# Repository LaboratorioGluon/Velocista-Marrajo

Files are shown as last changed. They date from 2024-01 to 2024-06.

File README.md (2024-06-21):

# Velocista Marrajo

Robot velocista para competición.

## Componentes Principales

- ESC 4-en-1: https://s.click.aliexpress.com/e/_DDoQeDV
- Motores Ruedas (2004 1750KV): https://es.aliexpress.com/item/1005005199386587.html
- Motor Succion (GR1404 3850KV):  https://s.click.aliexpress.com/e/_DeUeUJD
- Procesador (ESP32): https://s.click.aliexpress.com/e/_DCxmJWF
- Sensores (ITR8307): https://s.click.aliexpress.com/e/_DEY47Gr
- Rodamientos (MR128 8x12x3.5, x4): https://s.click.aliexpress.com/e/_DeULPyP
- Engranaje (7T 1.48mm): https://s.click.aliexpress.com/e/_DDH1tE3
- Engranaje (423A, x2): https://s.click.aliexpress.com/e/_DeBl3bN

## Renders

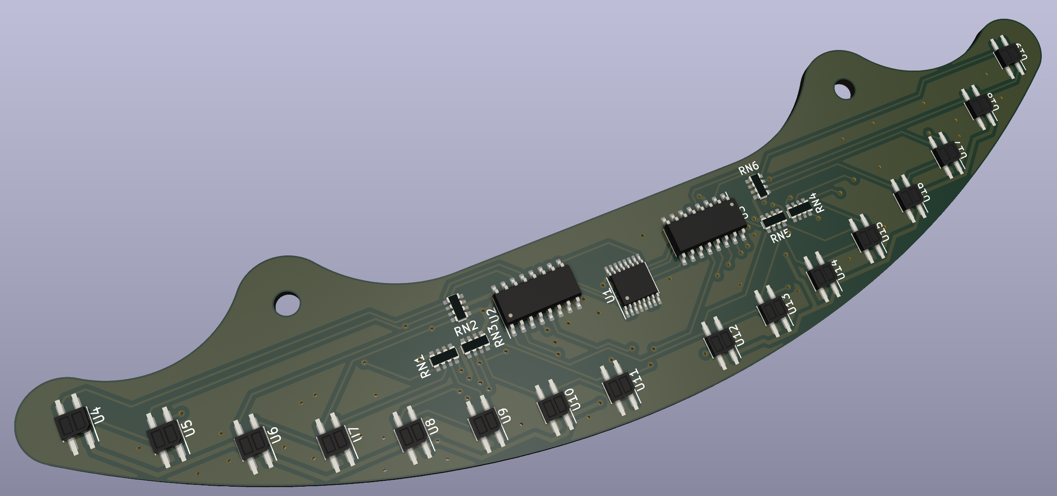
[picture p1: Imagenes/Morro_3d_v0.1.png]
Render Morro


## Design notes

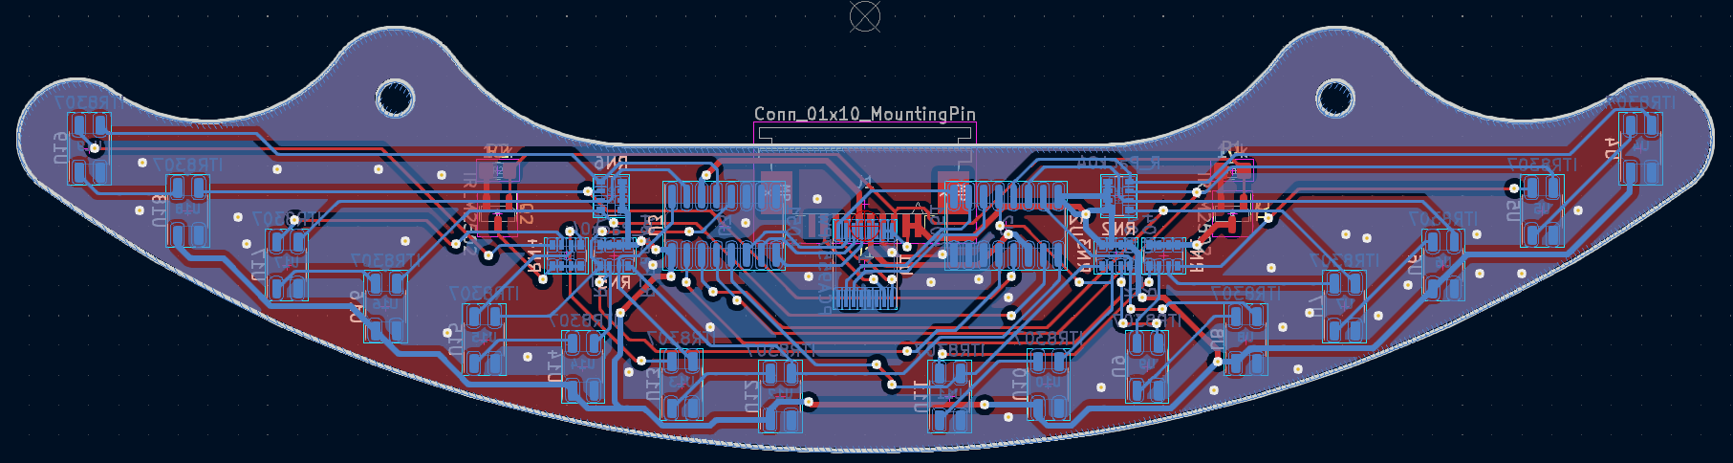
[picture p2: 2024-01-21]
Imagenes/Morro_PCB_v0.1.png

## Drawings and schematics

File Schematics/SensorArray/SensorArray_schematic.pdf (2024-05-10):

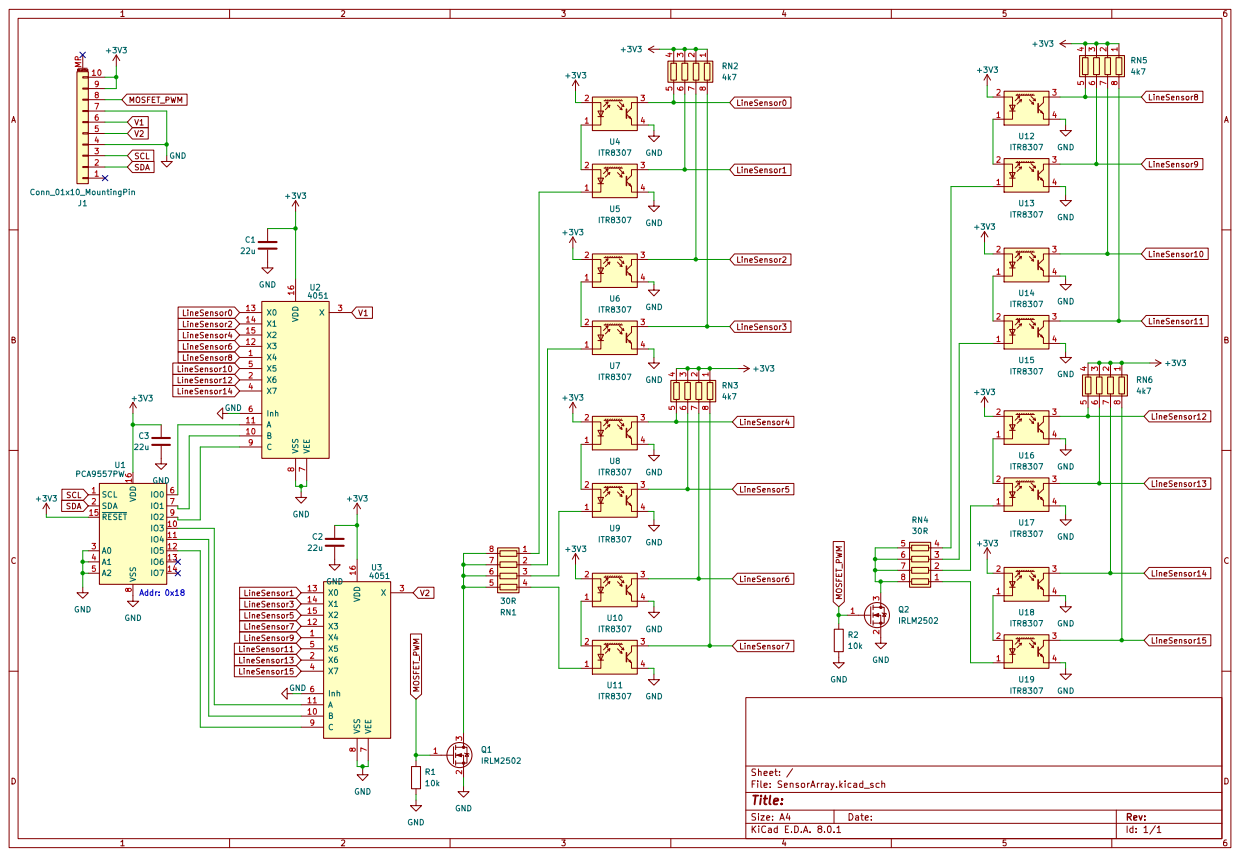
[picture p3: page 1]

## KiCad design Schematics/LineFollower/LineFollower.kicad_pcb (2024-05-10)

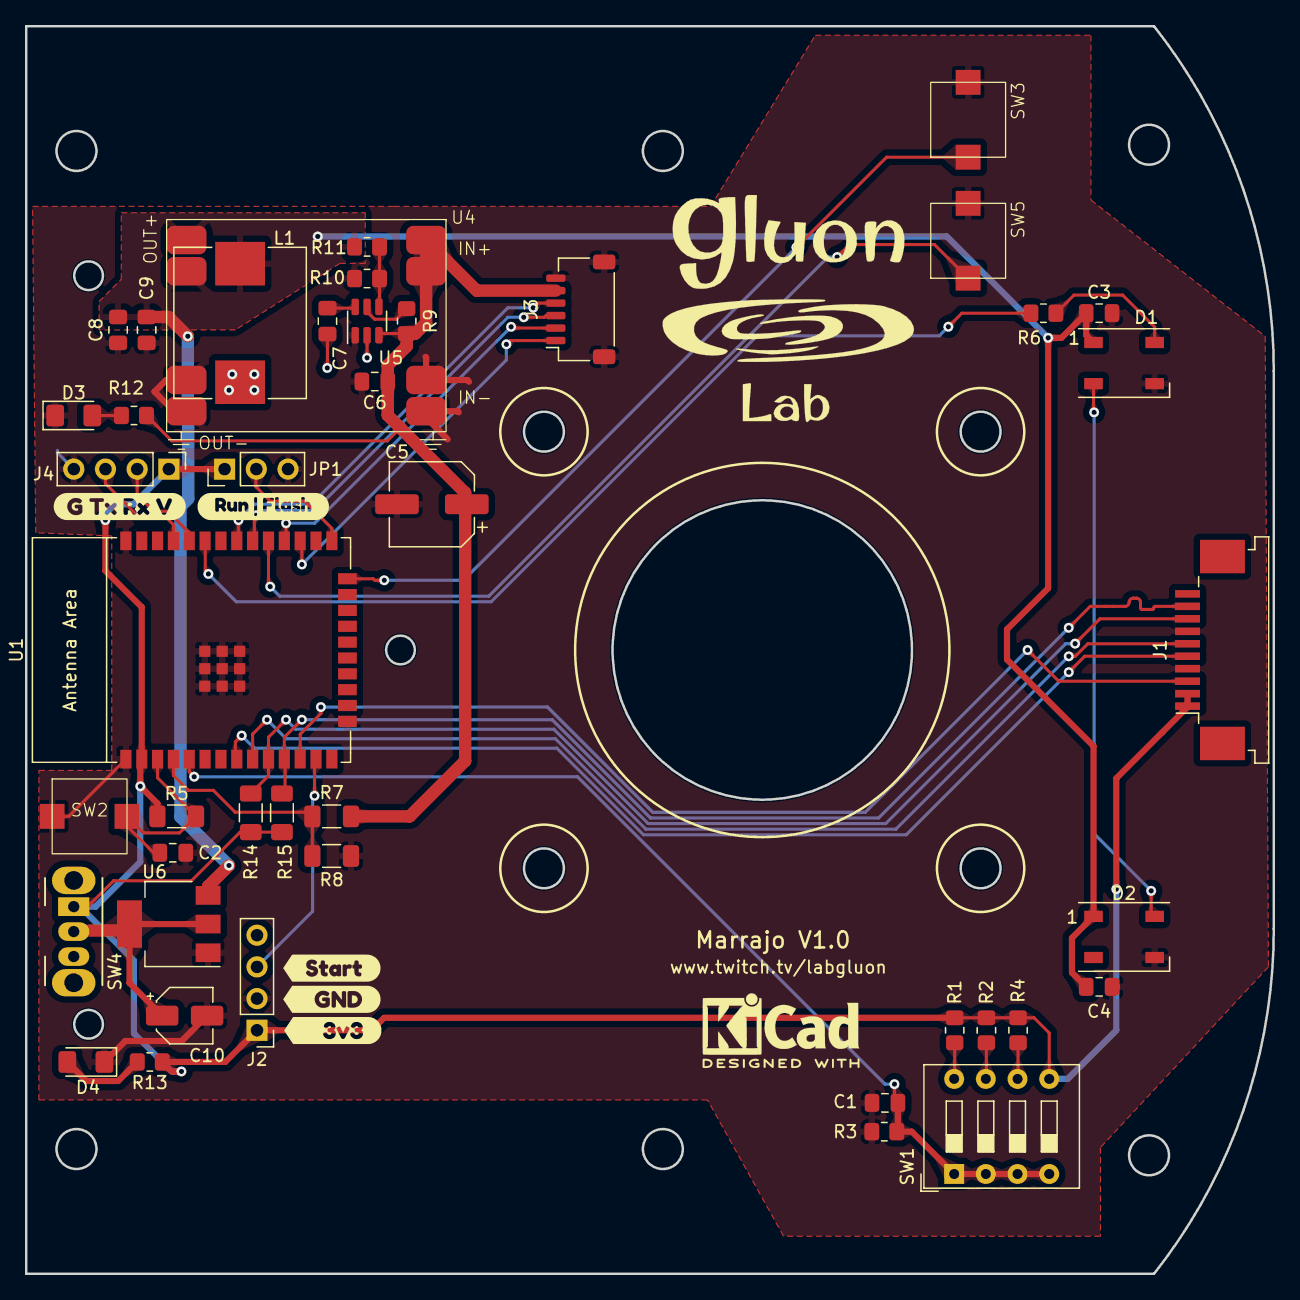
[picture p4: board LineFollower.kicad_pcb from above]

Board: 2 copper layers, 100.0 x 100.0 mm, 49 parts (0 on the bottom side), 35 nets.

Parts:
C1, C2, C3, C4: 100nF; C_0805_2012Metric_Pad1.18x1.45mm_HandSolder
C5: 100u; CP_Elec_6.3x5.4
C6, C8, C9: 22u; C_0805_2012Metric_Pad1.18x1.45mm_HandSolder
C7: 100n; C_0805_2012Metric_Pad1.18x1.45mm_HandSolder
C10: C_Polarized_US; CP_Elec_4x5.3
D1, D2: WS2812B; LED_WS2812B_PLCC4_5.0x5.0mm_P3.2mm
D3: vBatt; LED_1206_3216Metric_Pad1.42x1.75mm_HandSolder
D4: 3v3; LED_1206_3216Metric_Pad1.42x1.75mm_HandSolder
J1: Morro; TE_1-84952-0_1x10-1MP_P1.0mm_Horizontal
J2: StartModule; PinHeader_1x04_P2.54mm_Vertical
J3: 4en1; JST_SH_SM06B-SRSS-TB_1x06-1MP_P1.00mm_Horizontal
J4: UART; PinHeader_1x04_P2.54mm_Vertical
JP1: BOOT_SELECT; PinHeader_1x03_P2.54mm_Vertical
L1: 3u3; L_Chilisin_BMRF00101040
R1, R12: 4k7; R_0805_2012Metric_Pad1.20x1.40mm_HandSolder
R2, R3: 2k2; R_0805_2012Metric_Pad1.20x1.40mm_HandSolder
R4, R13: 1k; R_0805_2012Metric_Pad1.20x1.40mm_HandSolder
R5, R8: 10k; R_1206_3216Metric_Pad1.30x1.75mm_HandSolder
R6: 470; R_0805_2012Metric_Pad1.20x1.40mm_HandSolder
R7: 47k; R_1206_3216Metric_Pad1.30x1.75mm_HandSolder
R9, R10: 10k; R_0805_2012Metric_Pad1.20x1.40mm_HandSolder
R11: 54k9; R_0805_2012Metric_Pad1.20x1.40mm_HandSolder
R14, R15: 2k; R_1206_3216Metric_Pad1.30x1.75mm_HandSolder
SW1: SW_DIP_x04; SW_DIP_SPSTx04_Slide_9.78x12.34mm_W7.62mm_P2.54mm
SW2: SW_Push; SKPMANE010 _Silicone_6x6mm
SW3: Push2; SKPMANE010 _Silicone_6x6mm
SW4: SW_Push_SPDT; SS12D07VG2
SW5: Start; SKPMANE010 _Silicone_6x6mm
U1: ESP32-WROOM-E; ESP32-WROOM-32E
U4: 5v-Reg
U5: TPS563201; SOT-23-6
U6: AMS1117-3.3; SOT-223-3_TabPin2
kibuzzard-65DCBE20: G***; kibuzzard-65DCBE20
kibuzzard-65DCBE24: G***; kibuzzard-65DCBE24
kibuzzard-65DCBE28: G***; kibuzzard-65DCBE28
kibuzzard-65DCBF71: G***; kibuzzard-65DCBF71
kibuzzard-65DCBFCA: G***; kibuzzard-65DCBFCA

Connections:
+3V3: J1.1, J1.2, J2.1, J4.1, JP1.1 (A), R1.2, R2.2, R4.2, R5.2, R13.1, R14.2, R15.2, SW1.5, SW4.1 (A), U1.2 (3V3)
+5V: C3.1, C4.1, C8.1, C9.1, D1.1 (VDD), D2.1 (VDD), L1.2, R11.2, U4.3 (Vout), U6.3 (VI)
/BOOT_SELECT: JP1.2 (C), U1.25 (GPIO0/BOOT/ADC2_CH1)
/CONFIG: C1.1, R3.2, SW1.1, SW1.2, SW1.3, SW1.4, U1.5 (SENSOR_VN/GPIO39/ADC1_CH3)
/MOSFET_PWM: J1.3, U1.12 (ADC2_CH7/GPIO27)
/MOTOR_1: J3.1, U1.27 (GPIO16)
/MOTOR_2: J3.2, U1.28 (GPIO17)
/MOTOR_3: J3.3, U1.30 (GPIO18)
/MOTOR_4: J3.4, U1.31 (GPIO19)
/Power/3v3: C10.1, SW4.2 (B), U6.2 (VO)
/RGB_PIN: R6.2, U1.33 (GPIO21)
/SCL: J1.8, R14.1, U1.10 (DAC_1/ADC2_CH8/GPIO25)
/SDA: J1.9, R15.1, U1.11 (DAC_2/ADC2_CH9/GPIO26)
/START: J2.3, U1.13 (MTMS/GPIO14/ADC2_CH6)
/UART_RX: J4.2, U1.34 (U0RXD/GPIO3)
/UART_TX: J4.3, U1.35 (U0TXD/GPIO1)
/V1: J1.5, U1.8 (32K_XP/GPIO32/ADC1_CH4)
/V2: J1.6, U1.9 (32K_XN/GPIO33/ADC1_CH5)
/V_BATT: C5.1, C6.1, J3.5, R7.1, R9.2, R12.1, U4.1 (Vin), U5.3 (VIN)
/V_BATT_SENSE: R7.2, R8.1, U1.4 (SENSOR_VP/GPIO36/ADC1_CH0)
GND: C1.2, C2.2, C3.2, C4.2, C5.2, C6.2, C8.2, C9.2, C10.2, D1.3 (VSS), D2.3 (VSS), D3.1 (K), D4.1 (K), J1.4, J1.7, J2.2, J3.6, J3.MP (MountPin), J4.4, JP1.3 (B), R3.1, R8.2, R10.2, SW2.1, SW3.2, SW5.2, U1.1 (GND), U1.15 (GND), U1.38 (GND), U1.39 (GND_THERMAL), U4.2 (Gnd), U4.4 (Gnd), U5.1 (GND), U6.1 (GND)
unnamed: D1.4 (DIN), R6.1
unnamed: D1.2 (DOUT), D2.4 (DIN)
unnamed: D3.2 (A), R12.2
unnamed: D4.2 (A), R13.2
unnamed: R1.1, SW1.8
unnamed: R2.1, SW1.7
unnamed: R4.1, SW1.6
unnamed: SW3.1, U1.24 (ADC2_CH2/GPIO2)
unnamed: C2.1, R5.1, SW2.2, U1.3 (EN/CHIP_PU)
unnamed: SW5.1, U1.29 (GPIO5)
unnamed: R9.1, U5.5 (EN)
unnamed: C7.2, L1.1, U5.2 (SW)
unnamed: C7.1, U5.6 (VBST)
unnamed: R10.1, R11.1, U5.4 (VFB)

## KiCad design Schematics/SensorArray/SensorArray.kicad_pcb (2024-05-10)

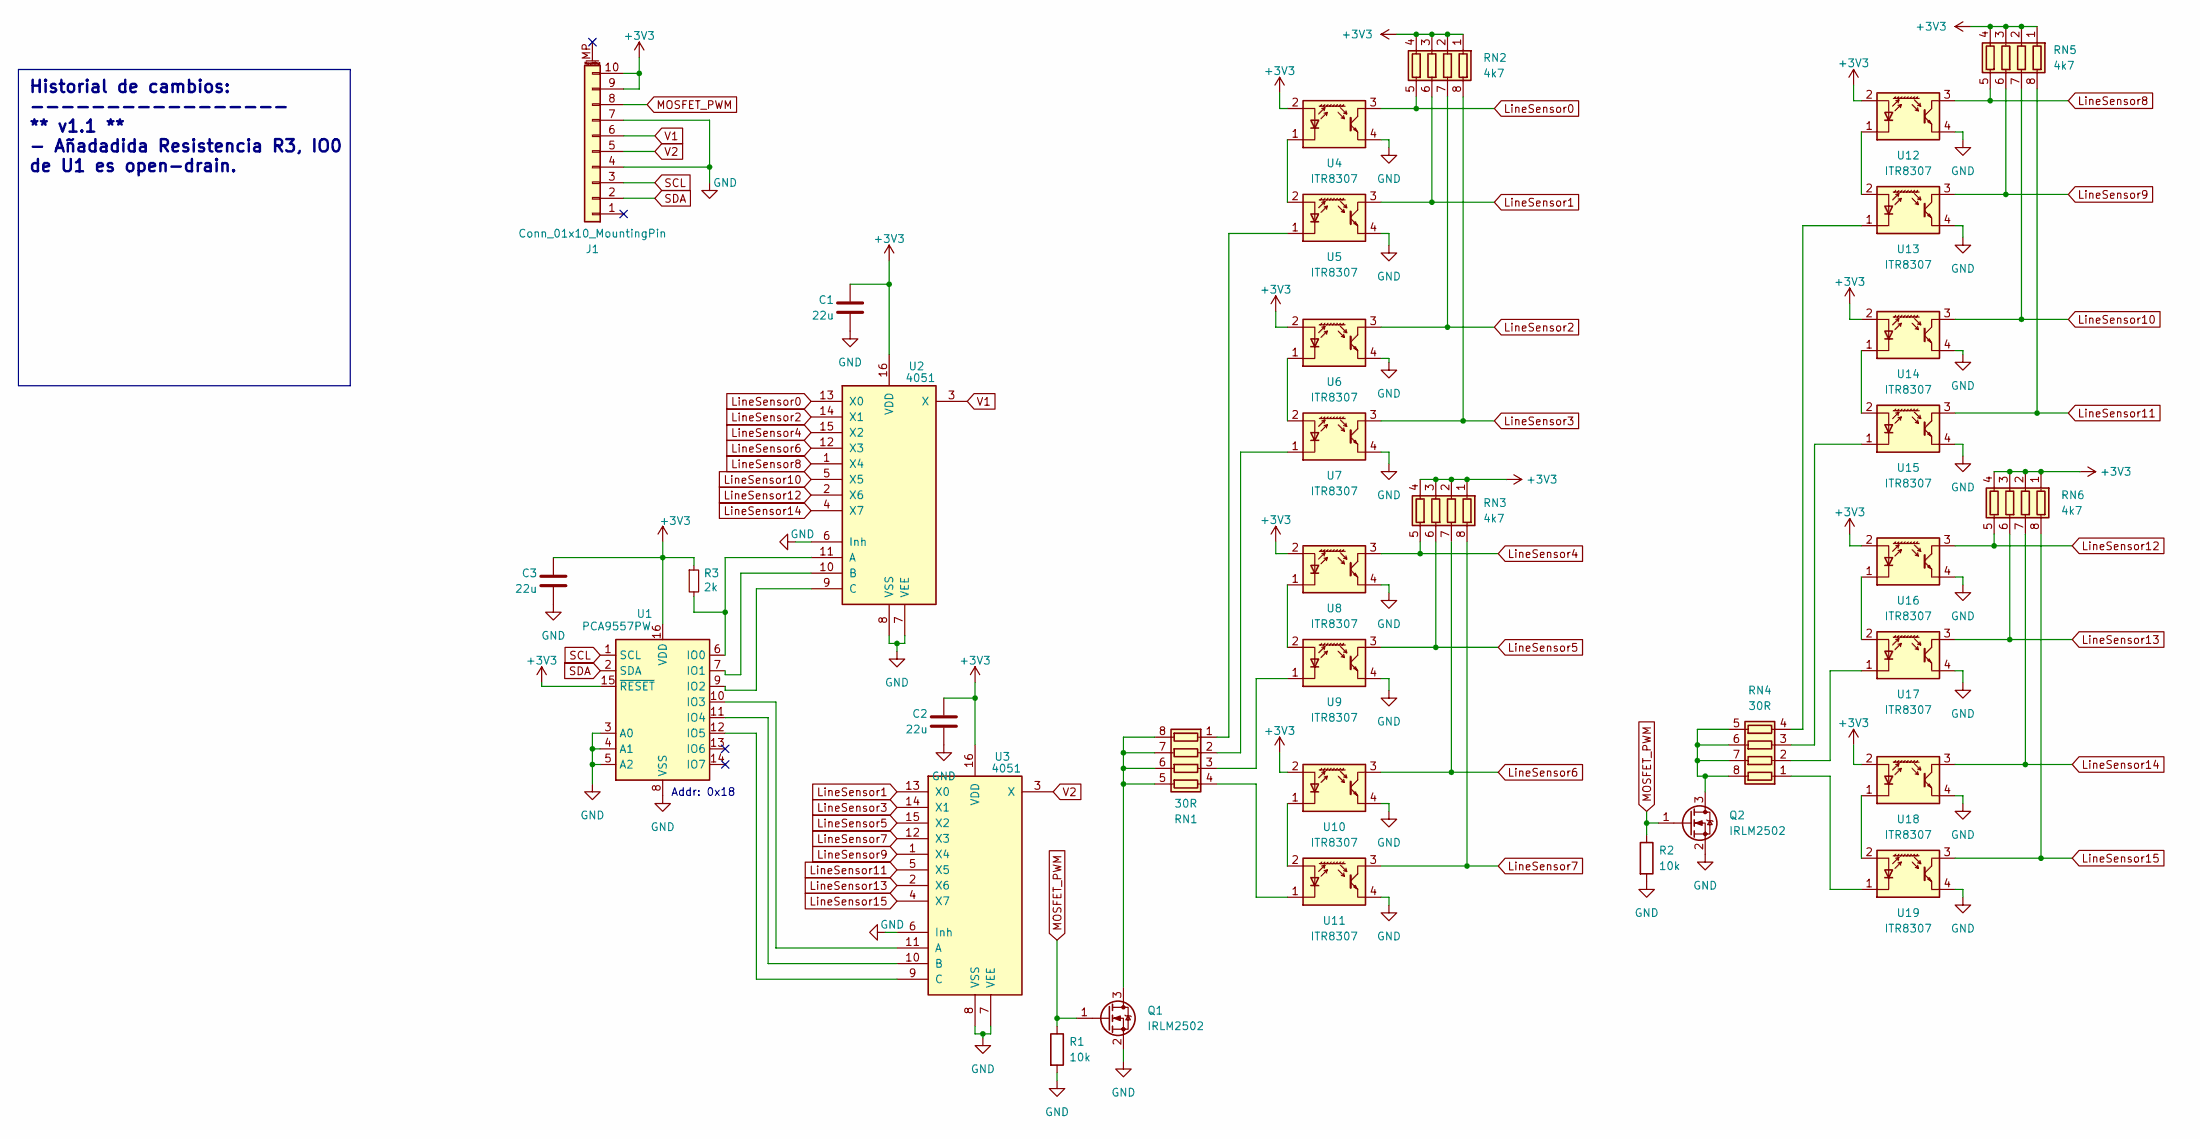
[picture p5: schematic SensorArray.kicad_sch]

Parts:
C1, C2, C3: 22u; C_0805_2012Metric_Pad1.18x1.45mm_HandSolder
J1: Conn_01x10_MountingPin; TE_1-84952-0_1x10-1MP_P1.0mm_Horizontal
Q1, Q2: IRLM2502; SOT-23
R1, R2: 10k; R_0805_2012Metric_Pad1.20x1.40mm_HandSolder
R3: 2k
RN1, RN4: 30R; R_Array_Convex_4x0603
RN2, RN3, RN5, RN6: 4k7; R_Array_Convex_4x0603
U1: PCA9557PW; TSSOP-16_4.4x5mm_P0.65mm
U2, U3: 4051; SOP-16_3.9x9.9mm_P1.27mm
U4, U5, U6, U7, U8, U9, U10, U11, U12, U13, U14, U15, U16, U17, U18, U19: ITR8307; Everlight_ITR1201SR10AR

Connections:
+3V3: C1.1, C2.1, C3.1, J1.9, J1.10, R3.1, RN2.1 (R1.1), RN2.2 (R2.1), RN2.3 (R3.1), RN2.4 (R4.1), RN3.1 (R1.1), RN3.2 (R2.1), RN3.3 (R3.1), RN3.4 (R4.1), RN5.1 (R1.1), RN5.2 (R2.1), RN5.3 (R3.1), RN5.4 (R4.1), RN6.1 (R1.1), RN6.2 (R2.1), RN6.3 (R3.1), RN6.4 (R4.1), U1.15 (~RESET), U1.16 (VDD), U2.16 (VDD), U3.16 (VDD), U4.2 (A), U6.2 (A), U8.2 (A), U10.2 (A), U12.2 (A), U14.2 (A), U16.2 (A), U18.2 (A)
GND: C1.2, C2.2, C3.2, J1.4, J1.7, Q1.2 (S), Q2.2 (S), R1.2, R2.2, U1.3 (A0), U1.4 (A1), U1.5 (A2), U1.8 (VSS), U2.6 (Inh), U2.7 (VEE), U2.8 (VSS), U3.6 (Inh), U3.7 (VEE), U3.8 (VSS), U4.4, U5.4, U6.4, U7.4, U8.4, U9.4, U10.4, U11.4, U12.4, U13.4, U14.4, U15.4, U16.4, U17.4, U18.4, U19.4
LineSensor0: RN2.5 (R4.2), U2.13 (X0), U4.3
LineSensor1: RN2.6 (R3.2), U3.13 (X0), U5.3
LineSensor2: RN2.7 (R2.2), U2.14 (X1), U6.3
LineSensor3: RN2.8 (R1.2), U3.14 (X1), U7.3
LineSensor4: RN3.5 (R4.2), U2.15 (X2), U8.3
LineSensor5: RN3.6 (R3.2), U3.15 (X2), U9.3
LineSensor6: RN3.7 (R2.2), U2.12 (X3), U10.3
LineSensor7: RN3.8 (R1.2), U3.12 (X3), U11.3
LineSensor8: RN5.5 (R4.2), U2.1 (X4), U12.3
LineSensor9: RN5.6 (R3.2), U3.1 (X4), U13.3
LineSensor10: RN5.7 (R2.2), U2.5 (X5), U14.3
LineSensor11: RN5.8 (R1.2), U3.5 (X5), U15.3
LineSensor12: RN6.5 (R4.2), U2.2 (X6), U16.3
LineSensor13: RN6.6 (R3.2), U3.2 (X6), U17.3
LineSensor14: RN6.7 (R2.2), U2.4 (X7), U18.3
LineSensor15: RN6.8 (R1.2), U3.4 (X7), U19.3
MOSFET_PWM: J1.8, Q1.1 (G), Q2.1 (G), R1.1, R2.1
unnamed: Q1.3 (D), RN1.5 (R4.2), RN1.6 (R3.2), RN1.7 (R2.2), RN1.8 (R1.2)
unnamed: Q2.3 (D), RN4.5 (R4.2), RN4.6 (R3.2), RN4.7 (R2.2), RN4.8 (R1.2)
unnamed: RN1.1 (R1.1), U5.1 (K)
unnamed: RN1.2 (R2.1), U7.1 (K)
unnamed: RN1.3 (R3.1), U9.1 (K)
unnamed: RN1.4 (R4.1), U11.1 (K)
unnamed: RN4.1 (R1.1), U19.1 (K)
unnamed: RN4.2 (R2.1), U17.1 (K)
unnamed: RN4.3 (R3.1), U15.1 (K)
unnamed: RN4.4 (R4.1), U13.1 (K)
unnamed: R3.2, U1.6 (IO0), U2.11 (A)
unnamed: U1.7 (IO1), U2.10 (B)
unnamed: U1.9 (IO2), U2.9 (C)
unnamed: U1.10 (IO3), U3.11 (A)
unnamed: U1.11 (IO4), U3.10 (B)
unnamed: U1.12 (IO5), U3.9 (C)
unnamed: U4.1 (K), U5.2 (A)
unnamed: U6.1 (K), U7.2 (A)
unnamed: U8.1 (K), U9.2 (A)
unnamed: U10.1 (K), U11.2 (A)
unnamed: U12.1 (K), U13.2 (A)
unnamed: U14.1 (K), U15.2 (A)
unnamed: U16.1 (K), U17.2 (A)
unnamed: U18.1 (K), U19.2 (A)
SCL: J1.3, U1.1 (SCL)
SDA: J1.2, U1.2 (SDA)
V1: J1.6, U2.3 (X)
V2: J1.5, U3.3 (X)

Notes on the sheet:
Historial de cambios: ----------------- ** v1.1 ** - Añadadida Resistencia R3, IO0 de U1 es open-drain.
Addr: 0x18

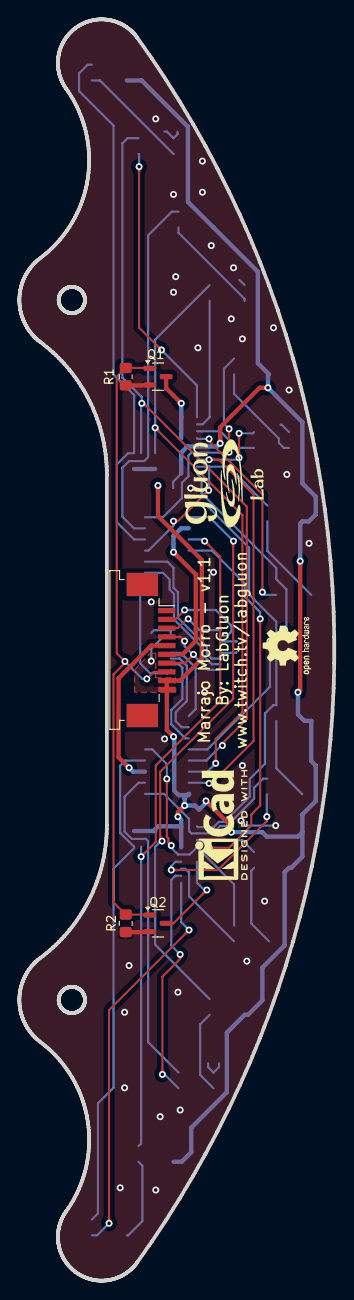
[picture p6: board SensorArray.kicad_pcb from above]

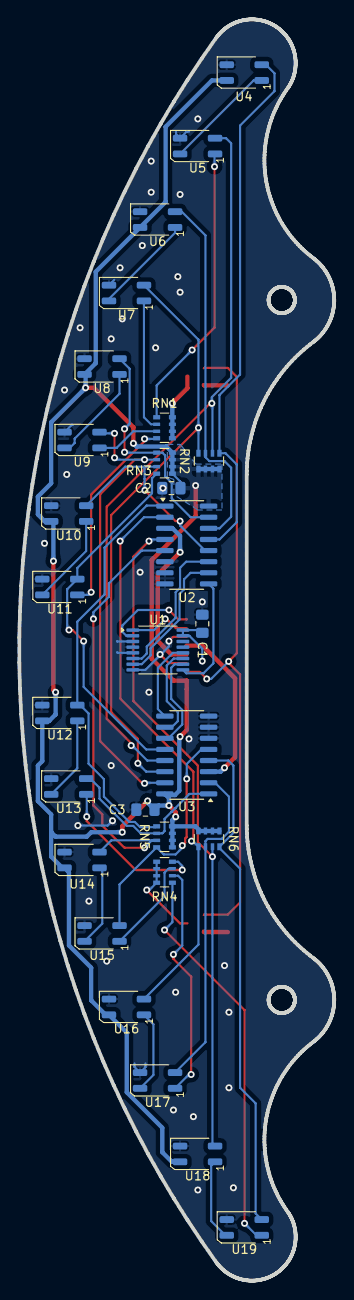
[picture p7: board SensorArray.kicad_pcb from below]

Board: 2 copper layers, 36.0 x 144.2 mm, 33 parts (28 on the bottom side), 47 nets.

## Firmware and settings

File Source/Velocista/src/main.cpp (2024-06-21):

#include <nvs_flash.h>
#include <driver/gpio.h>
#include "driver/adc.h"
#include <BtRobotController.h>
#include <driver/ledc.h>
#include "esp_log.h"

#include "comms/BTCommands.h"
#include "comms/wifi.h"
#include "comms/ota.h"

#include "common/pid.h"
#include "common/log.h"

#include "HwDevices.h"
#include "drivers/led_strip_encoder.h"
#include "driver/rmt_tx.h"

#include "comms/udp_serial.h"

const char *TAG = "MAIN";

/***** EJEMPLO WS2812 ******/
#define EXAMPLE_LED_NUMBERS 2
#define EXAMPLE_CHASE_SPEED_MS 10

static uint8_t led_strip_pixels[EXAMPLE_LED_NUMBERS * 3];

extern "C" void app_main();

PID motorPid(0.1f, 0, 0);
UdpSerial uSerial("192.168.1.133", 5005);

char waitForChar()
{
    char b;
    do
    {
        b = getchar();
        vTaskDelay(pdMS_TO_TICKS(100));
    } while (b == 0xFF);
    return b;
}

TaskHandle_t statusTask;

void taskLoop(void *arg)
{
    while (1)
    {
        status.loop(100);
        vTaskDelay(pdMS_TO_TICKS(100));
    }
}

TaskHandle_t morroTask;

float meanspeed = 40.0f;
float targetSpeed = 65.0f;
uint8_t stopOrder = 0;
void taskMorro(void *arg)
{

    int32_t motorR = 0;
    int32_t motorL = 0;
    uint64_t startTime = 0;
    uint64_t dt = 1;
    int32_t pidOutput;
    int32_t linePos = 0;
    int32_t newLinePos = 0;
    MORRO_RET lineStatus = MORRO_LINE_OK;
    struct logInfo info;
    uSerial.printf("Starting!!!\n");
    while (1)
    {

        if (status.getStatus() == STATUS::OTA_UPDATE)
        {
            vTaskDelay(100);
            continue;
        }

        lineStatus = morro.getLinePosition(newLinePos);

        if ( lineStatus == MORRO_LINE_LOST || stopOrder == 1)
        {
            // Stop all
            motor1.setPowerPercentage(0);
            motor2.setPowerPercentage(0);
            succion.setPowerPercentage(0);
            status.setStatus(SECURITY_STOP);
            dumpDataToUdp(uSerial);
            stopOrder = 0;
            while(1)
            {
                status.setStatus(WAITING_START);   
                while(phyinputs.getInput(1) == 1)
                {
                    vTaskDelay(100);
                }
                linePos = 0;
                startTime = 0;
                meanspeed = 40.0f;
                resetLog();
                uSerial.printf("reStarting!!!\n");
                printf("ReStarting!\n");
                status.setStatus(NOMINAL);
                vTaskDelay(pdMS_TO_TICKS(1000));
                break;
            }
        }

        linePos = 0.9 * newLinePos + 0.1 * linePos;

        // printf("%ld\n", linePos);
        if (startTime != 0)
        {
            dt = esp_timer_get_time() - startTime;
            pidOutput = (int32_t)motorPid.update(linePos, dt/1000.0f);
        }
        else
        {
            pidOutput = 0;
        }
        startTime = esp_timer_get_time();

        motorR = 0.8 * (meanspeed + pidOutput) + 0.2 * motorR;
        motorL = 0.8 * (meanspeed - pidOutput) + 0.2 * motorR;

        motorR = (motorR > 80) ? 80 : motorR;
        motorL = (motorL > 80) ? 80 : motorL;

        motorR = (motorR < 0) ? 0 : motorR;
        motorL = (motorL < 0) ? 0 : motorL;

        motor1.setPowerPercentage(motorR);
        motor2.setPowerPercentage(motorL);

        if (meanspeed < targetSpeed)
        {
            meanspeed += dt * 10 / 1000000.0f;
        }

        info.linePos = linePos;
        info.pidOutput = pidOutput;
        info.motorR = motorR;
        info.motorL= motorL;
        info.dt = dt;
        storeLoopInfo(info);
        //uSerial.printf("%ld %ld %ld %llu\n", linePos, motorR, motorL, dt);
        // printf("(%ld) %-5ld %-5ld\n",pidOutput, motorR, motorL);

        // vTaskDelay(2);

#if 0
        startTime=esp_timer_get_time();
        morro.getLinePosition();
        stopTime = esp_timer_get_time();
        printf("Delta: %llu\n", stopTime-startTime);
        startTime = stopTime;
#endif
    }
}

void app_main()
{
    nvs_flash_init();

    leds.init();
    status.setLedController(&leds);
    status.setStatus(OTA_AND_BT_OK);
    xTaskCreatePinnedToCore(taskLoop, "Status_Task", 4096, NULL, 9, &statusTask, 0);
    wifi_init_sta();
    startOtaTask(1, 0);
    robotCtrl.Init("MARRAJO", robotConfig, 7);
    phyinputs.init();
    uSerial.Init();

 
#if 0
        //vTaskDelay(pdMS_TO_TICKS(0));
        /*motor1.Init(250, 125, 250, 1);
        motor2.Init(250, 125, 250);
        succion.Init(250, 125, 250);*/
        printf("Connect the ESC now!\n");
        printf("Wait for 2 beeps from the ESC and press a key\n");

        waitForChar();
        motor1.setPowerPercentage(0);
        motor2.setPowerPercentage(0);
        succion.setPowerPercentage(0);
        printf("Wait for 1,2,3 beeps \n");
        waitForChar();
#else
    motor1.Init(125, 125, 250, 1);
    motor2.Init(125, 125, 250);
    succion.Init(125, 125, 250);
    vTaskDelay(pdMS_TO_TICKS(5000));
#endif
    

    printf("Ready!\n");
    status.setStatus(MOTORS_OK);
    morro.init();

    /*uint16_t values[16] = {0};
    while (1)
    {
        for (uint8_t i = 0; i < ARRAY_NUM_SENSOR / 2; i++)
        {
            // updateAndReadSensorArrayRaw(2 * i, 2 * i + 1, tempValueE, tempValueO);
            sensors.configExpander(2 * i, 2 * i + 1);
            sensors.readSensors(values[2 * i], values[2 * i + 1]);
            // updateCalibration(2 * i, tempValueE);
            // updateCalibration(2 * i + 1, tempValueO);
        }
        printf("data: ");
        for (uint8_t i = 0; i < ARRAY_NUM_SENSOR; i++)
        {
            printf("%-5u ", values[i]);
        }
        printf("\n");
    }*/

    status.setStatus(CALIBRATING);
    uint32_t cnt = 0;
    while (morro.calibrate() == 0 && status.getStatus() != OTA_UPDATE)
    {
        cnt++;
        if(cnt == 1000)
        {
            uSerial.printf("Dato motor: %.2f\n", succion.getPowerPercentage());
            cnt = 0;
        }
        
    }
    if (status.getStatus() == OTA_UPDATE)
    {
        sensors.stopAdc();
        while (1)
            ;
    }
    status.setStatus(WAITING_START);
    while (phyinputs.getInput(0) == 1 && status.getStatus() != OTA_UPDATE)
    {
        morro.calibrate();
    }
    vTaskDelay(pdMS_TO_TICKS(300));
    while (phyinputs.getInput(0) == 0);
    status.setStatus(MOTORS_OK);
    vTaskDelay(pdMS_TO_TICKS(1000));
    while (phyinputs.getInput(0) == 1);
    status.setStatus(NOMINAL);
    morro.searchLinePosition();
    vTaskDelay(pdMS_TO_TICKS(3000));
    xTaskCreatePinnedToCore(taskMorro, "Morro_Task", 4096, NULL, 9, &morroTask, 1);
    uint8_t isWifiInit = 0;

    while (1)
    {
        vTaskDelay(pdMS_TO_TICKS(500));
    }
}

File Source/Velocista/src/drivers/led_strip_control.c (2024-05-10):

/*
 * SPDX-FileCopyrightText: 2021-2022 Espressif Systems (Shanghai) CO LTD
 *
 * SPDX-License-Identifier: Apache-2.0
 */

#if 1
#include "esp_check.h"
#include "drivers/led_strip_encoder.h"

static const char *TAG = "led_encoder";

typedef struct {
    rmt_encoder_t base;
    rmt_encoder_t *bytes_encoder;
    rmt_encoder_t *copy_encoder;
    int state;
    rmt_symbol_word_t reset_code;
} rmt_led_strip_encoder_t;

static size_t rmt_encode_led_strip(rmt_encoder_t *encoder, rmt_channel_handle_t channel, const void *primary_data, size_t data_size, rmt_encode_state_t *ret_state)
{
    rmt_led_strip_encoder_t *led_encoder = __containerof(encoder, rmt_led_strip_encoder_t, base);
    rmt_encoder_handle_t bytes_encoder = led_encoder->bytes_encoder;
    rmt_encoder_handle_t copy_encoder = led_encoder->copy_encoder;
    rmt_encode_state_t session_state = RMT_ENCODING_RESET;
    rmt_encode_state_t state = RMT_ENCODING_RESET;
    size_t encoded_symbols = 0;
    switch (led_encoder->state) {
    case 0: // send RGB data
        encoded_symbols += bytes_encoder->encode(bytes_encoder, channel, primary_data, data_size, &session_state);
        if (session_state & RMT_ENCODING_COMPLETE) {
            led_encoder->state = 1; // switch to next state when current encoding session finished
        }
        if (session_state & RMT_ENCODING_MEM_FULL) {
            state |= RMT_ENCODING_MEM_FULL;
            goto out; // yield if there's no free space for encoding artifacts
        }
    // fall-through
    case 1: // send reset code
        encoded_symbols += copy_encoder->encode(copy_encoder, channel, &led_encoder->reset_code,
                                                sizeof(led_encoder->reset_code), &session_state);
        if (session_state & RMT_ENCODING_COMPLETE) {
            led_encoder->state = RMT_ENCODING_RESET; // back to the initial encoding session
            state |= RMT_ENCODING_COMPLETE;
        }
        if (session_state & RMT_ENCODING_MEM_FULL) {
            state |= RMT_ENCODING_MEM_FULL;
            goto out; // yield if there's no free space for encoding artifacts
        }
    }
out:
    *ret_state = state;
    return encoded_symbols;
}

static esp_err_t rmt_del_led_strip_encoder(rmt_encoder_t *encoder)
{
    rmt_led_strip_encoder_t *led_encoder = __containerof(encoder, rmt_led_strip_encoder_t, base);
    rmt_del_encoder(led_encoder->bytes_encoder);
    rmt_del_encoder(led_encoder->copy_encoder);
    free(led_encoder);
    return ESP_OK;
}

static esp_err_t rmt_led_strip_encoder_reset(rmt_encoder_t *encoder)
{
    rmt_led_strip_encoder_t *led_encoder = __containerof(encoder, rmt_led_strip_encoder_t, base);
    rmt_encoder_reset(led_encoder->bytes_encoder);
    rmt_encoder_reset(led_encoder->copy_encoder);
    led_encoder->state = RMT_ENCODING_RESET;
    return ESP_OK;
}

esp_err_t rmt_new_led_strip_encoder(const led_strip_encoder_config_t *config, rmt_encoder_handle_t *ret_encoder)
{
    esp_err_t ret = ESP_OK;
    rmt_led_strip_encoder_t *led_encoder = NULL;
    ESP_GOTO_ON_FALSE(config && ret_encoder, ESP_ERR_INVALID_ARG, err, TAG, "invalid argument");
    //led_encoder = rmt_alloc_encoder_mem(sizeof(rmt_led_strip_encoder_t));
    led_encoder = calloc(1, sizeof(rmt_led_strip_encoder_t));
    ESP_GOTO_ON_FALSE(led_encoder, ESP_ERR_NO_MEM, err, TAG, "no mem for led strip encoder");
    led_encoder->base.encode = rmt_encode_led_strip;
    led_encoder->base.del = rmt_del_led_strip_encoder;
    led_encoder->base.reset = rmt_led_strip_encoder_reset;
    // different led strip might have its own timing requirements, following parameter is for WS2812
    rmt_bytes_encoder_config_t bytes_encoder_config = {
        .bit0 = {
            .level0 = 1,
            .duration0 = 0.3 * config->resolution / 1000000, // T0H=0.3us
            .level1 = 0,
            .duration1 = 0.9 * config->resolution / 1000000, // T0L=0.9us
        },
        .bit1 = {
            .level0 = 1,
            .duration0 = 0.9 * config->resolution / 1000000, // T1H=0.9us
            .level1 = 0,
            .duration1 = 0.3 * config->resolution / 1000000, // T1L=0.3us
        },
        .flags.msb_first = 1 // WS2812 transfer bit order: G7...G0R7...R0B7...B0
    };
    ESP_GOTO_ON_ERROR(rmt_new_bytes_encoder(&bytes_encoder_config, &led_encoder->bytes_encoder), err, TAG, "create bytes encoder failed");
    rmt_copy_encoder_config_t copy_encoder_config = {};
    ESP_GOTO_ON_ERROR(rmt_new_copy_encoder(&copy_encoder_config, &led_encoder->copy_encoder), err, TAG, "create copy encoder failed");

    uint32_t reset_ticks = config->resolution / 1000000 * 50 / 2; // reset code duration defaults to 50us
    led_encoder->reset_code = (rmt_symbol_word_t) {
        .level0 = 0,
        .duration0 = reset_ticks,
        .level1 = 0,
        .duration1 = reset_ticks,
    };
    *ret_encoder = &led_encoder->base;
    return ESP_OK;
err:
    if (led_encoder) {
        if (led_encoder->bytes_encoder) {
            rmt_del_encoder(led_encoder->bytes_encoder);
        }
        if (led_encoder->copy_encoder) {
            rmt_del_encoder(led_encoder->copy_encoder);
        }
        free(led_encoder);
    }
    return ret;
}
#endif

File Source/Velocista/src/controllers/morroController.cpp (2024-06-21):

#include "controllers/morroController.h"


// @TODO: delete me
#include "comms/udp_serial.h"
extern UdpSerial uSerial;

morroController::morroController(sensorArray &pSensors) : sensors(pSensors)
{
    aCurrentSensors[0] = 7;
    aCurrentSensors[1] = 8;

    isCalibrationCompleted = 0;
    for (uint8_t i = 0; i < ARRAY_NUM_SENSOR; i++)
    {
        calLowValue[i] = 1024;
        calHighValue[i] = 0;
        calDistance[i] = calHighValue[i] - calLowValue[i];
    }
}

void morroController::init()
{
    //sensors.init();
    sensors.initCont();
}

uint8_t morroController::calibrate()
{
    uint16_t tempValueE, tempValueO;

    for (uint8_t i = 0; i < ARRAY_NUM_SENSOR / 2; i++)
    {
        updateAndReadSensorArrayRaw(2 * i, 2 * i + 1, tempValueE, tempValueO);
        updateCalibration(2 * i, tempValueE);
        updateCalibration(2 * i + 1, tempValueO);
    }

    int16_t minDist = 9999;
    isCalibrationCompleted = 1;
    for (uint8_t i = 0; i < ARRAY_NUM_SENSOR; i++)
    {
        if (calDistance[i] < minDist)
        {
            minDist = calDistance[i];
        }
        printf("%d ", calDistance[i]);
        //uSerial.printf("%d ", calDistance[i]);
    }
    printf("\n");
    /*uSerial.printf("==Cal Data");
    for ( uint8_t i = 0; i < ARRAY_NUM_SENSOR; i++)
    {
        uSerial.printf("Cal[%u]: %u %u", i, calLowValue[i], calHighValue[i]);
    }
    uSerial.printf("==Cal Data End");*/
    
    if (minDist < 300)
    {
        isCalibrationCompleted = 0;
    }
    return isCalibrationCompleted;
}

uint8_t morroController::updateCalibration(uint8_t sensorIndex, uint16_t newValue)
{
    if (newValue < calLowValue[sensorIndex])
    {
        calLowValue[sensorIndex] = newValue;
        calDistance[sensorIndex] = calHighValue[sensorIndex] - calLowValue[sensorIndex];
    }
    if (newValue > calHighValue[sensorIndex])
    {
        calHighValue[sensorIndex] = newValue;
        calDistance[sensorIndex] = calHighValue[sensorIndex] - calLowValue[sensorIndex];
    }
    return 0;
}

MORRO_RET morroController::getLinePosition(int32_t& linePos)
{
    updateSensorsToRead();
    MORRO_RET lineStatus = MORRO_LINE_LOST;

    updateAndReadSensorArray(sensorsToRead[1], sensorsToRead[2], sensorsToReadData[1], sensorsToReadData[2]);
    updateAndReadSensorArray(sensorsToRead[0], sensorsToRead[3], sensorsToReadData[0], sensorsToReadData[3]);

    //printf("getPosition time: %llu\n", esp_timer_get_time()- startTime);

    if ( sensorsToReadData[0] < 50 &&
         sensorsToReadData[1] < 50 &&
         sensorsToReadData[2] < 50 &&
         sensorsToReadData[3] < 50)
    {
        uSerial.printf("========== Line lost!\n");
        // Give 5 oportunities to find the lane, otherwise give up.
        for( int i = 0; i < 5 && lineStatus == MORRO_LINE_LOST; i++)
        {
            lineStatus = searchLinePosition();
        }
        if (lineStatus == MORRO_LINE_LOST)
        {
            return lineStatus;
        }
    }


    if (sensorsToReadData[3] > 50 && sensorsToReadData[1] < 50 && aCurrentSensors[1] < 14)
    {
        aCurrentSensors[0]++;
        aCurrentSensors[1]++;
    }
    else if (sensorsToReadData[0] > 50 && sensorsToReadData[2] < 50 && aCurrentSensors[0] > 1)
    {
        aCurrentSensors[0]--;
        aCurrentSensors[1]--;
    }

    int32_t acum = 0;
    int32_t weightened = 0;
    float score[4] = {1.0f, 1, 1, 1.0f};
    for (uint8_t i = 0; i < 4; i++)
    {
        weightened += ((float)sensorsToReadData[i])*score[i] * ((float)sensorsToRead[i] - ((16.0f - 1.0f) /2.0f)) * 100;
        acum += sensorsToReadData[i];
    }
    if (acum == 0)
    {
        acum = 1;
    }

    linePos = (int32_t)weightened / acum;
    return MORRO_LINE_OK;
}


MORRO_RET morroController::searchLinePosition()
{
    uint16_t tempValueE, tempValueO;

    for (uint8_t i = 0; i < ARRAY_NUM_SENSOR / 2; i++)
    {
        updateAndReadSensorArray(2 * i, 2 * i + 1, tempValueE, tempValueO);
        if (tempValueE > 50 && tempValueO > 50)
        {
            aCurrentSensors[0] = 2 * i;
            aCurrentSensors[1] = 2 * i + 1;
            return MORRO_LINE_OK;
        }
        else if (tempValueE > 50)
        {
            aCurrentSensors[0] = 2 * i - 1;
            aCurrentSensors[1] = 2 * i;
            return MORRO_LINE_OK;
        }
        else if (tempValueO > 50)
        {
            aCurrentSensors[0] = 2 * i + 1;
            aCurrentSensors[1] = 2 * i + 2;
            return MORRO_LINE_OK;
        }
    }

    return MORRO_LINE_LOST;
}

void morroController::updateSensorsToRead()
{
    sensorsToRead[1] = aCurrentSensors[0];
    sensorsToRead[2] = aCurrentSensors[1];

    sensorsToRead[0] = sensorsToRead[1] - 1;
    sensorsToRead[3] = sensorsToRead[2] + 1;
}



void morroController::updateAndReadSensorArrayRaw(uint32_t v1, uint32_t v2, uint16_t &datav1, uint16_t &datav2)
{
    if (v1 % 2 == 0)
    {
        sensors.configExpander(v1, v2);
        sensors.readSensors(datav1, datav2);
    }
    else
    {
        sensors.configExpander(v2, v1);
        sensors.readSensors(datav2, datav1);
    }

}

void morroController::updateAndReadSensorArray(uint32_t v1, uint32_t v2, uint16_t &datav1, uint16_t &datav2)
{
    
    updateAndReadSensorArrayRaw(v1, v2 , datav1, datav2);
    // Normalizamos los datos de 0 a 100
    /*long map(long x, long in_min, long in_max, long out_min, long out_max) {
        return (x - in_min) * (out_max - out_min) / (in_max - in_min) + out_min;
    }*/

    if ( datav1 < calLowValue[v1])
    {
        datav1 = 0;
    }else
    {
        datav1 = (datav1 - calLowValue[v1]) * 100 / calDistance[v1];
    }
    if ( datav2 < calLowValue[v2])
    {
        datav2 = 0;
    }else
    {
        datav2 = (datav2 - calLowValue[v2]) * 100 / calDistance[v2];
    }

}

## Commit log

2024-03-15 Uploaded V1.0 of PCB
    [LineFollower.kicad_pcb, LineFollower.kicad_sch, SensorArray.kicad_pcb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]
2024-05-10 Version 1.1 PCB: Fixed I2C pullups
    [LineFollower.kicad_pcb, LineFollower.kicad_sch, SensorArray.kicad_pcb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]
2024-05-10 SW: Calibration ready
    [ota_partition.csv]
